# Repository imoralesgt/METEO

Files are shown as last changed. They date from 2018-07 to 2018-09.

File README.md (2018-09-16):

# METEO
## TFM MSEEI Universidad de Malaga
## Iván René Morales Argueta - 2018

===========================================================

# ToDo List
## Meteo
- [x] Connect to MQTT Broker in object constructor
	* [x] Subscribe to each ```Settings``` sub-topic ```Settings/#```
	* [ ] \(Optional) _Show performance and broker info by subscribing to special $SYS topics (https://www.hivemq.com/blog/mqtt-essentials-part-5-mqtt-topics-best-practices)_
- [x] Sample each sensor using separate threads
	* [x] Create a generic sampling method (one-shot), which receives the sensor name as parameter
		- [x] ```sampleSensor (sensorName)```
		- [x] Front-end interface variables (i.e. Air Quality, instead of Humidity+Gas_Resistance)
	- [x] Create a thread/method to periodically launch the one-shot sampling method
	* [x] Generate as many threads running this method as required
	* [ ] ~~Kill sampling threads during object destruction~~ Destructor not compatible with threaded implementation
	* [X] Implement a mutual-exclusion mechanism to avoid access violations
- [x] Send sensors' data via MQTT using topics to distribute data into different channels
- [x] Each "METEO" station MUST have a vaild (integer type) identifier, starting from 0
- [x] Topics should accomplish with the following template:
	* [x] ```METEO/<stationNumber>/Data/<sensor>```
	* [x] Valid ```<stationNumber>``` (identifiers) are integers from 0 to N-1
	* [x] Valid ```<sensor>``` values are:
		- [x] Temperature (Environmental temperature) [temp]
		- [x] Humidity (Relative humidity) [hum]
		- [x] Pressure (Local atmospheric pressure) [pres]
		- [x] Light (Incident light measurement) [light]
		- [x] AirQuality (Air quality as pollution measurement) [airQ]
		- [ ] ~~PPM (Raw particle count) [ppm]~~ PPM is irrelevant. Instead, PPM field used to transmit raw gas resistance value
- [x] A special topic may be used to set/get the sampling period dymanically
	* [x] ```METEO/<stationNumber>/Settings/SamplingRate/<sensor>```
	* [x] ```<sensor>``` field (sub-topic) is the same as described before
	* [x] Sampling rate value must be validated to remain between a valid range
		- [x] Min sampling rate 1 minute
		- [x] Max sampling rate 120 minutes
		- [x] If a sampling rate (SR) out of these limits is set, a default value will be chosen if a prior valid SR wasn't set yet; otherwise, the last valid SR will remain active
- [ ] \(Optional) _A special topic may be used to remotely reboot the device if no Alive beacons have been received_
	- [ ] _```METEO/<stationNumber>/Setiings/Reboot```_
	- [ ] _A unique key must be sent as password (through ```Reboot``` topic) to force a reboot_
	- [ ] _Key will be ```stationNumber```-dependent and time-dependent (unix format) hash_
	- [ ] _Hash must be computed by UI_
- [x] A special topic may be used to announce "I'm Alive" messages from stations to broker
	* [x] Invoke it via a separate thread as it may behave as a locking method
	* [x] ```METEO/Alive```
	* [x] Each station should publish a message containing only its ```<stationNumber>``` periodically (ie. every 1 minute)

## Printed circuit board
- [x] Design a PCB to place the sensor boards and the User-Interaction hardware (push-button + LED)
	- [x] Design must be compatible with Raspberry PI 3 header footprint
	- [x] Power must be supplied from Raspberry PI's 3v3/GND breakout pins
	- [x] Manufacture PCB and test functionality

## BME680_METEO
- [x] Compute Air Quality (%) using Humidity and Gas measurements
- [ ] ~~Compute PPM using Gas Baseline and Gas measurements~~ Not a requirement. Discarded from further releases.

## User Interaction
- [x] Add an LED status indicator to show whether the server is running or not (using RPI-GPIO)
- [x] Add a push-button input to hard-reset the server via a separate thread if anything fails (using RPI-GPIO)

## Data management
- [x] Grab sensors' data from MQTT broker and process it to deliver filtered information 
- [x] Store the processed data into a SQLite database
- [x] Retreive data from Broker and append it to a table within in the DB (running in parallel thread?)
- [x] Export table's content to a CSV when required
- [x] If several measurements from different sensors retreived within the same MINUTE, store them in the same register row.
- [x] If several measurements form the same sensor retreived within the same MINUTE, average grabbed values and then store the last average computation.

## Reliability
- [x] Run meteo.py as a standalone application
	- [x] Set flag to meteo.py
		- [x] ```chmod +x meteo.py```
- [x] Autorun on boot
	- [x] ```sudo crontab -e```
	- [x] ```@reboot /home/pi/METEO/meteo.py &```
- [x] Software Watchdog Timer
	- [x] Run a parallel process (subscribed to ```ALIVE``` topic) to check whether METEO is running or not
	- [x] Restart METEO process after 3 consecutive ```ALIVE``` periods with no answer
	- [x] Start WDT timer after the first ```ALIVE``` message arrives

# User interface
- [x] Node-RED User Interface

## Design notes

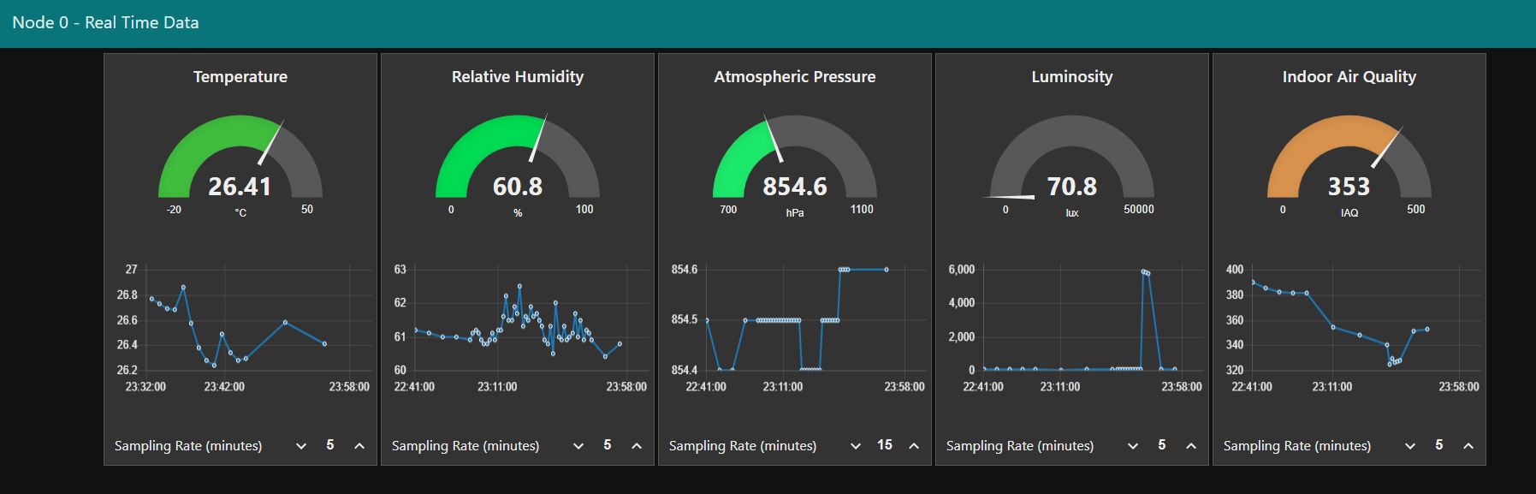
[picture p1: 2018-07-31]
gui/guiPreview.PNG

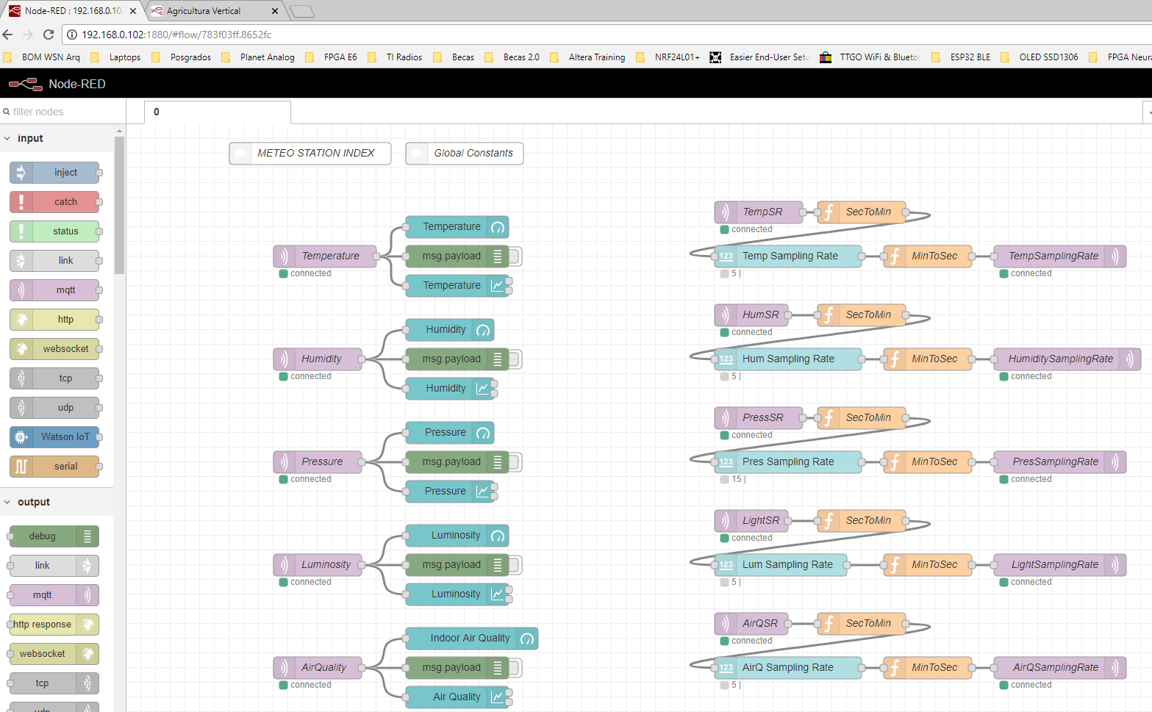
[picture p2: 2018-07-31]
gui/guiNodeRed.PNG

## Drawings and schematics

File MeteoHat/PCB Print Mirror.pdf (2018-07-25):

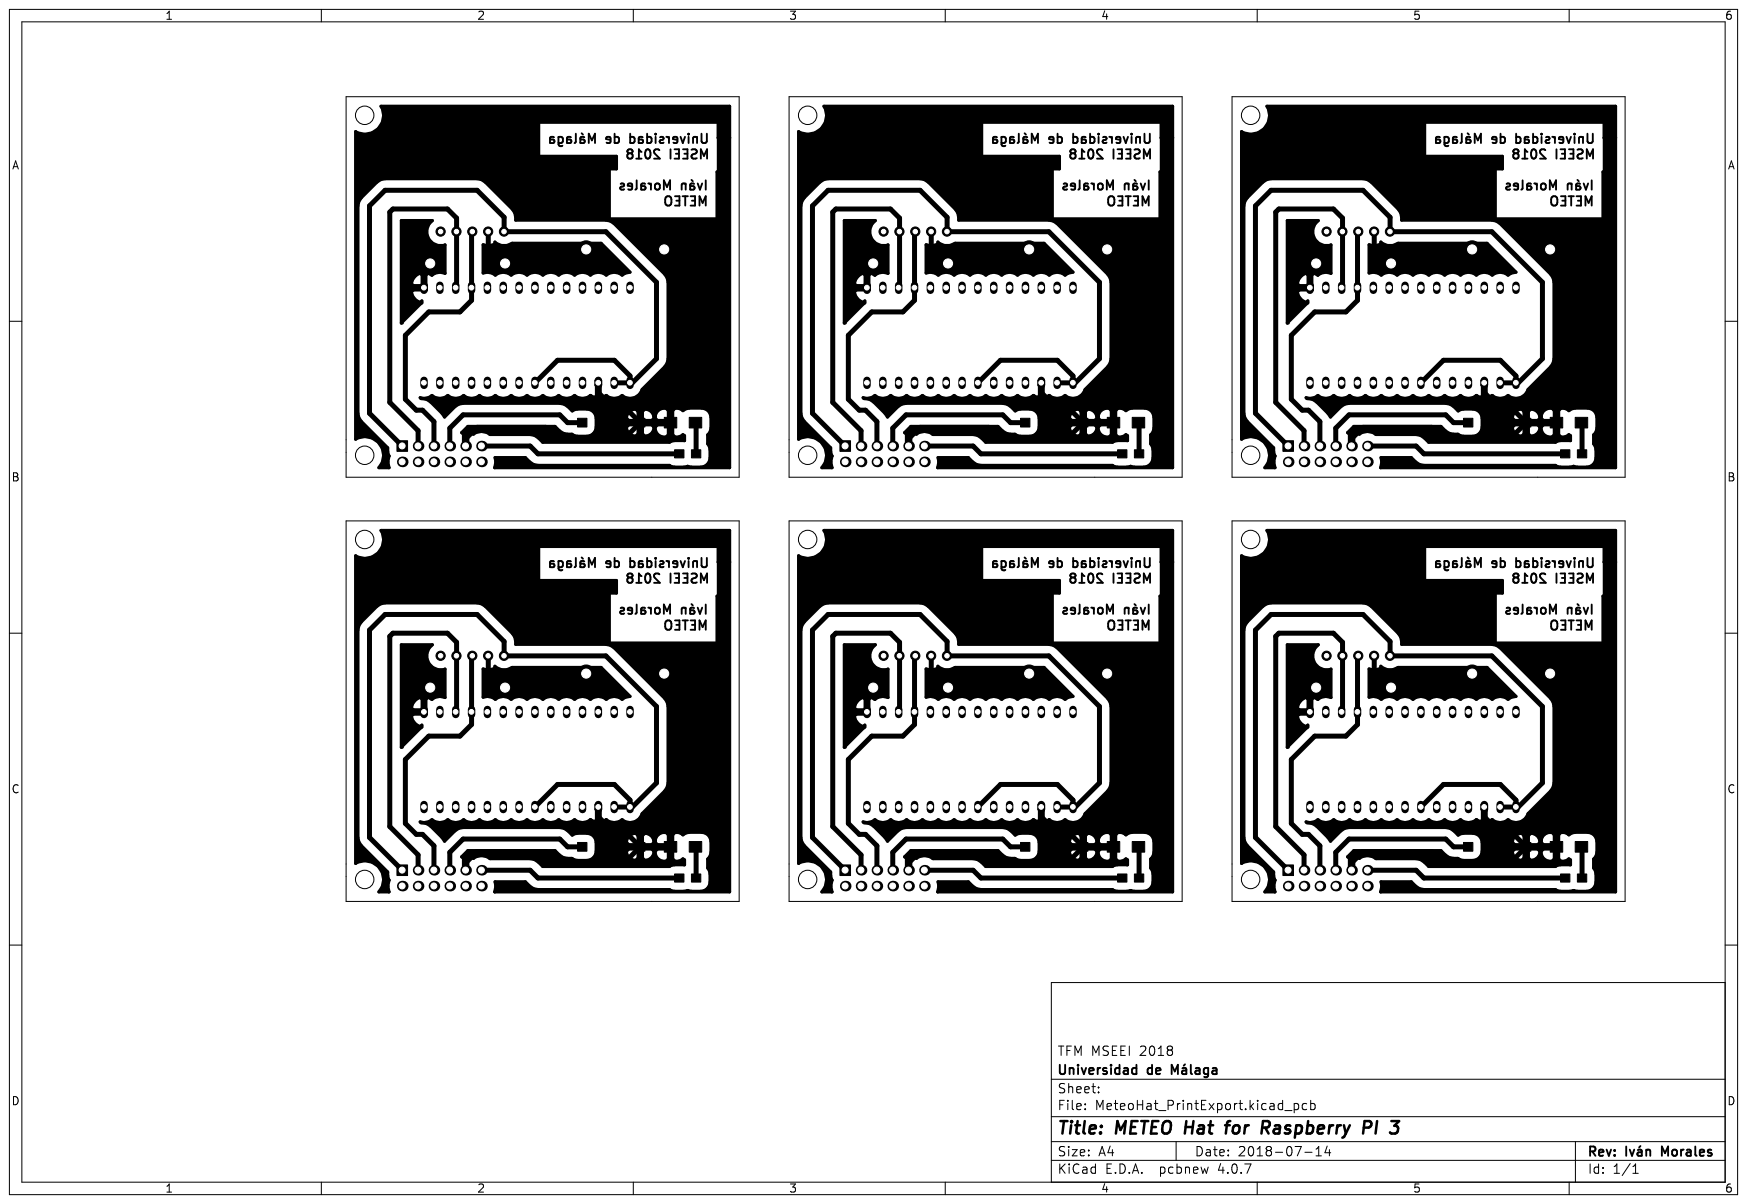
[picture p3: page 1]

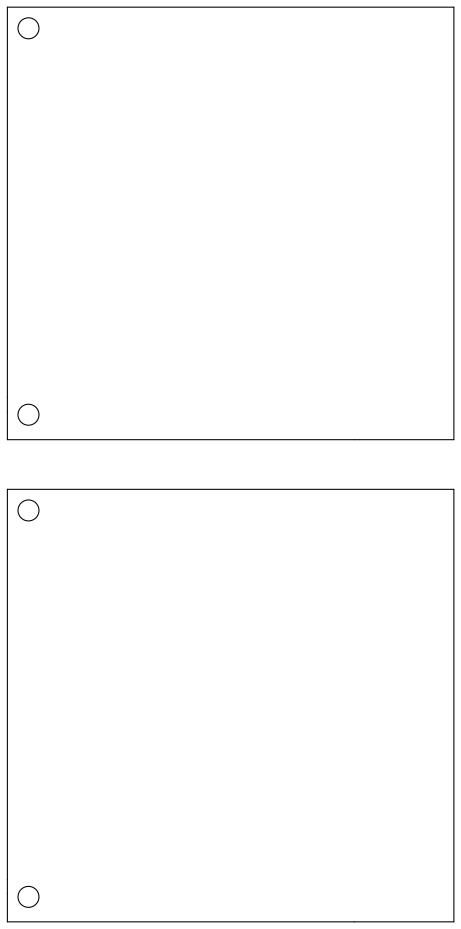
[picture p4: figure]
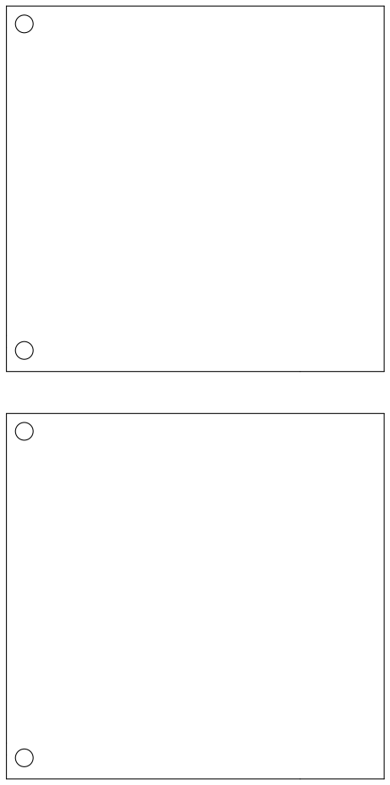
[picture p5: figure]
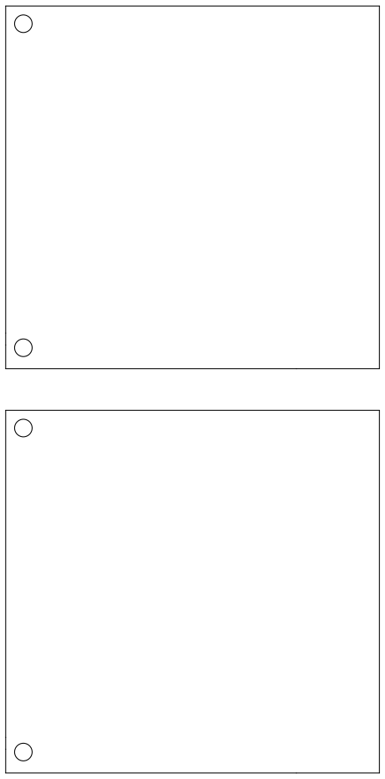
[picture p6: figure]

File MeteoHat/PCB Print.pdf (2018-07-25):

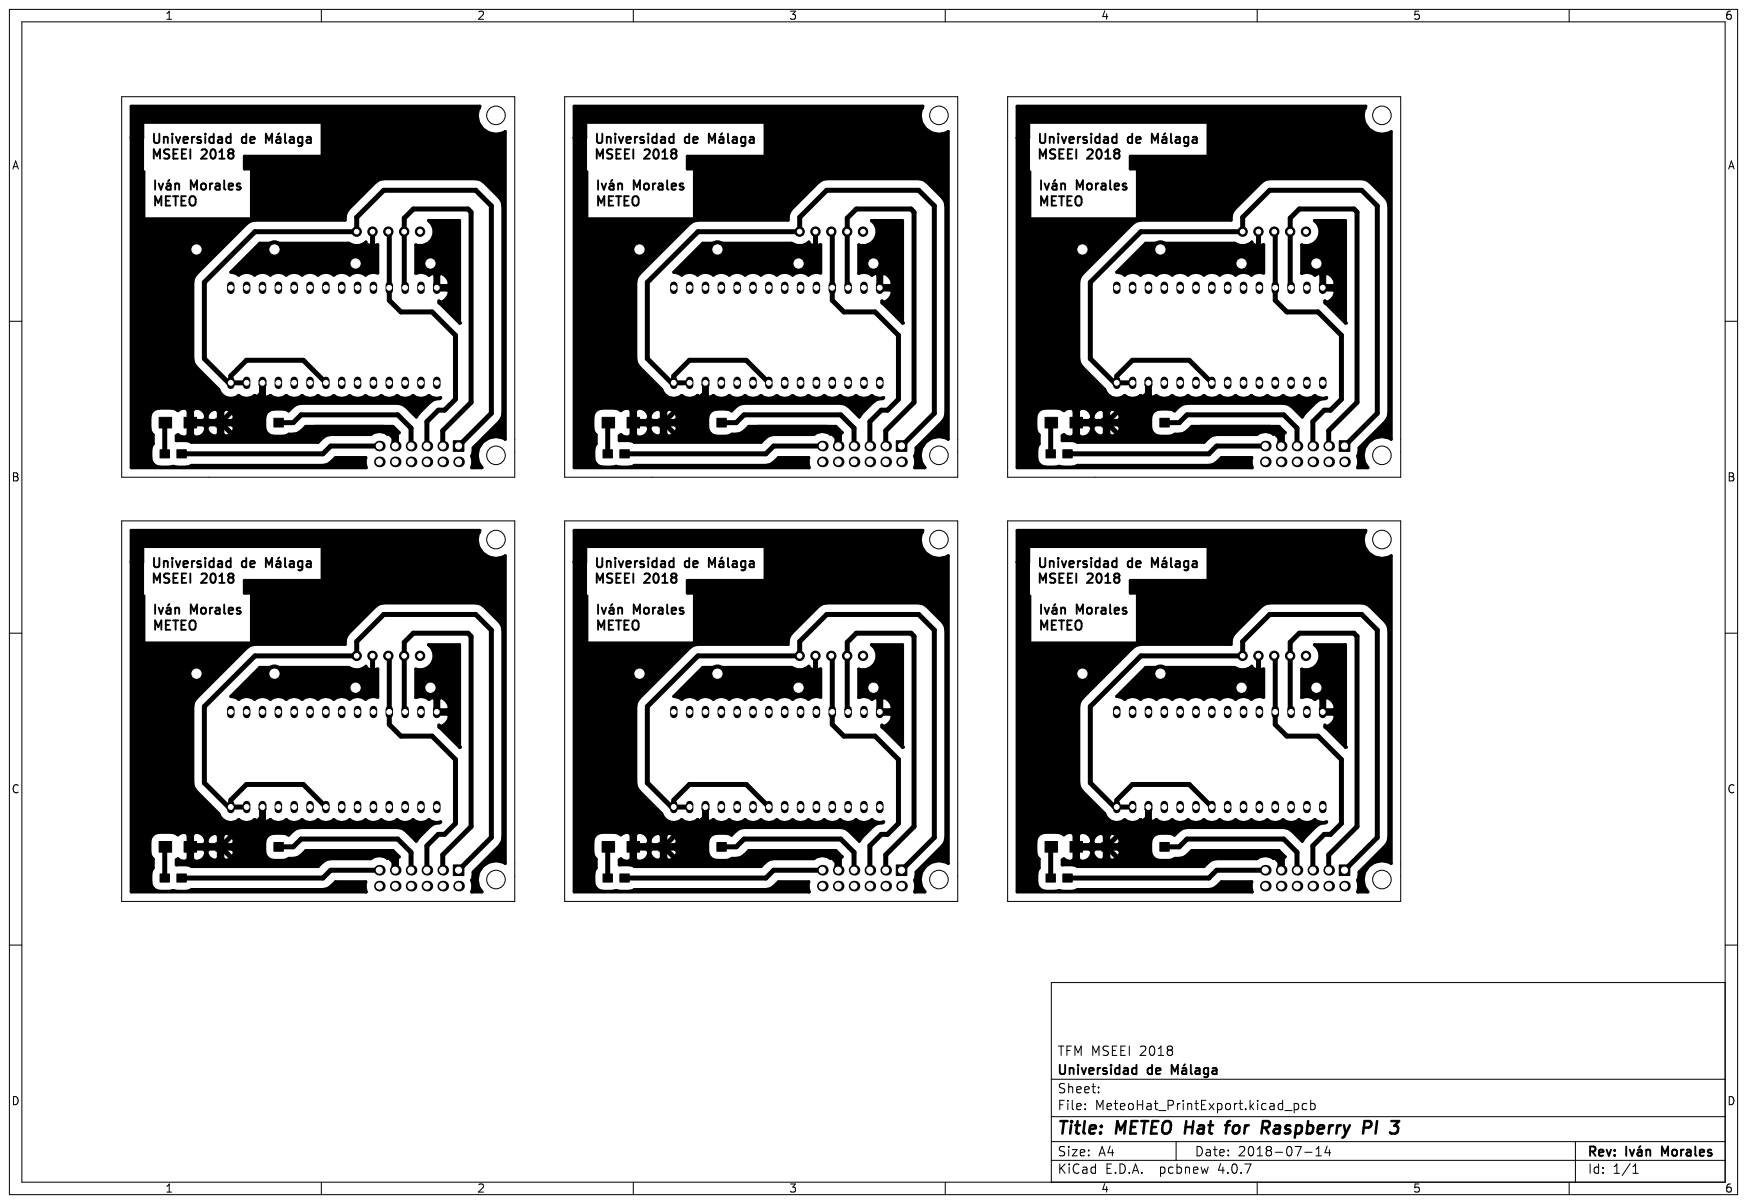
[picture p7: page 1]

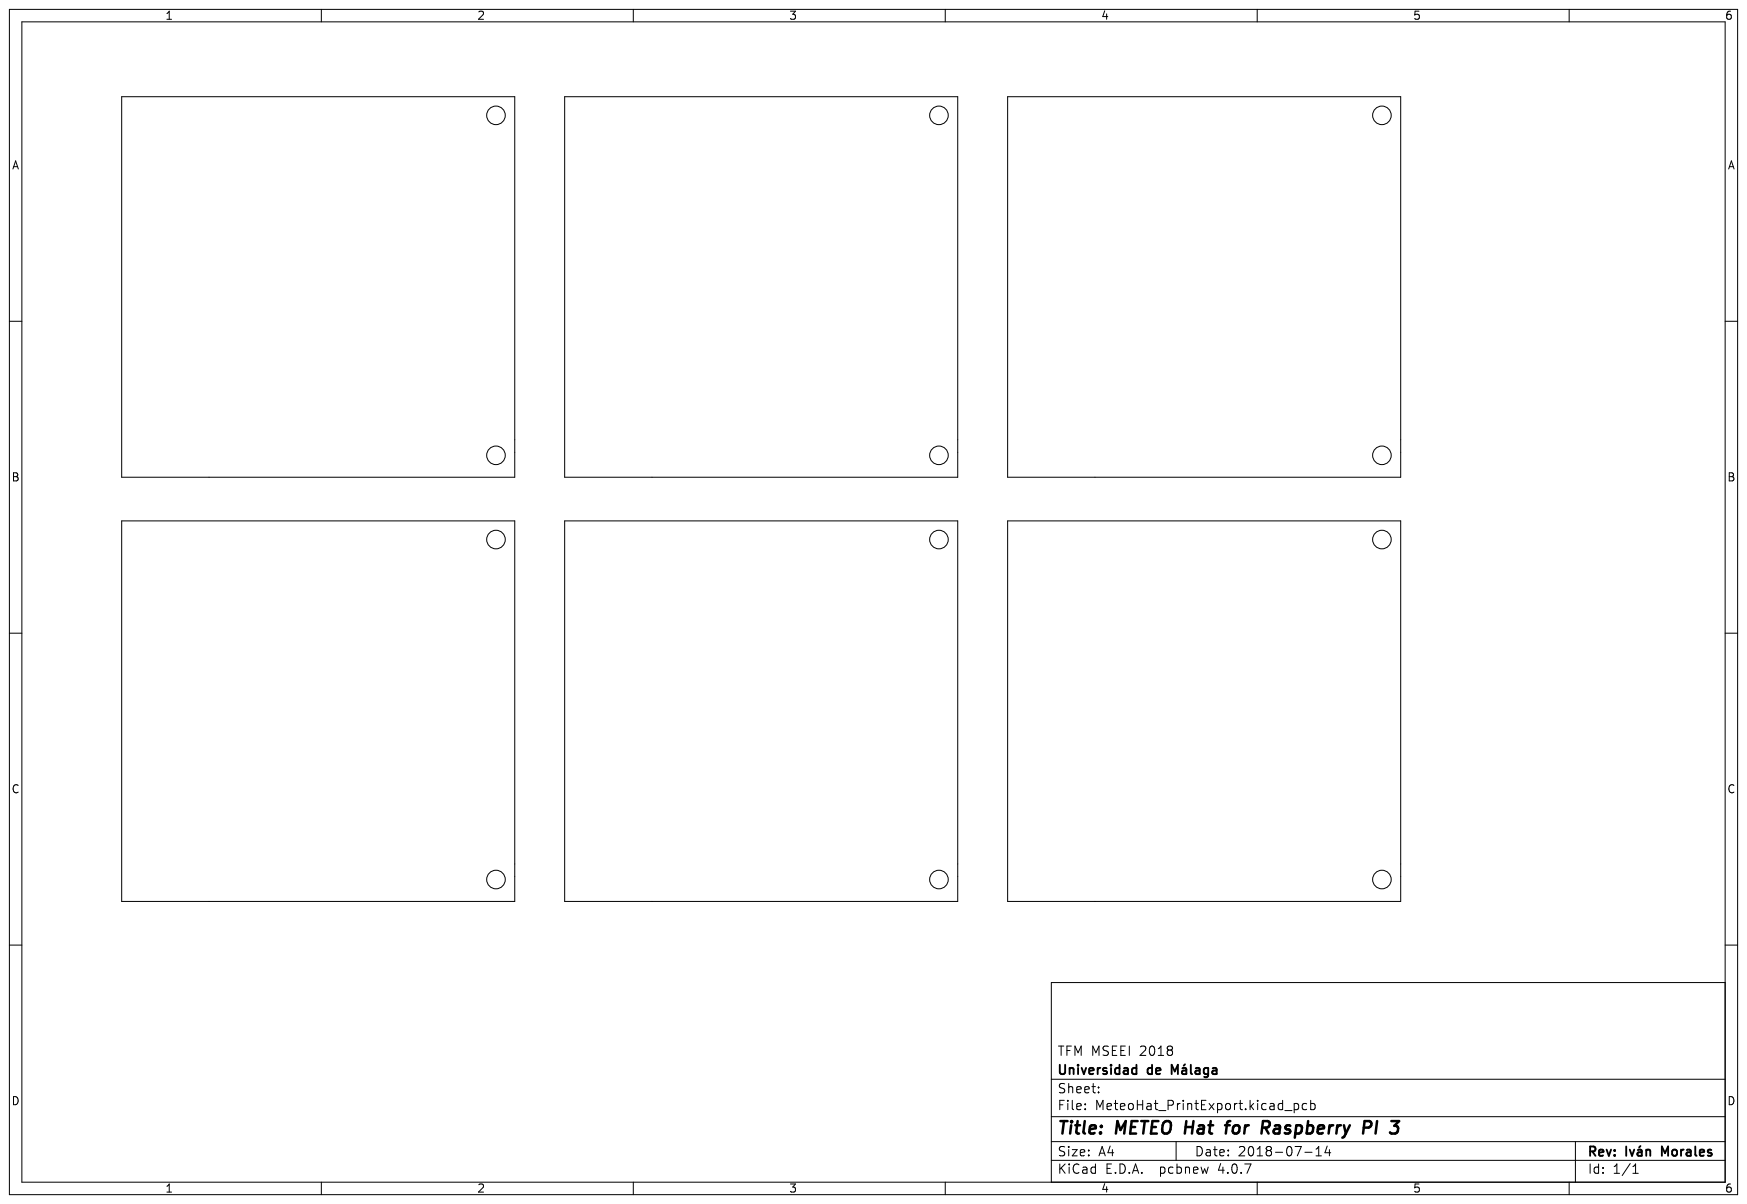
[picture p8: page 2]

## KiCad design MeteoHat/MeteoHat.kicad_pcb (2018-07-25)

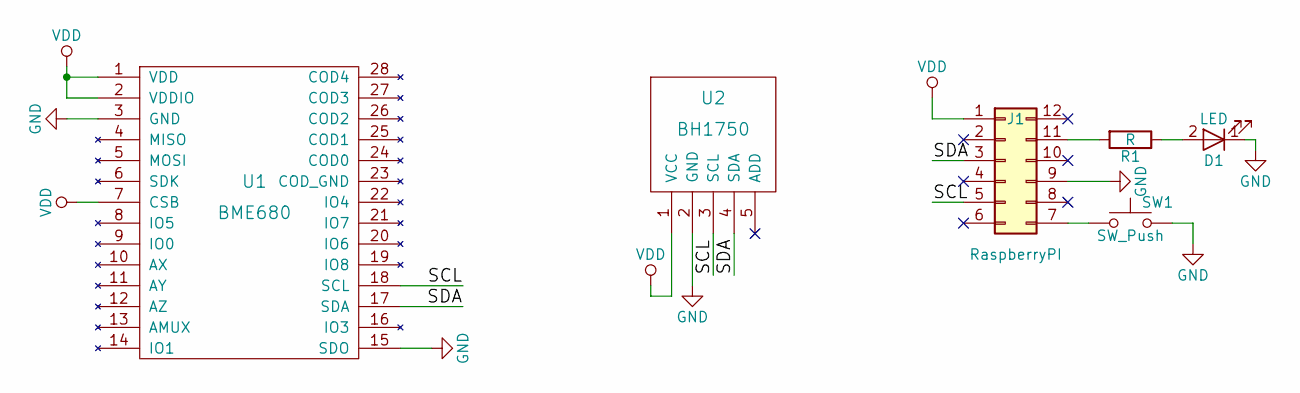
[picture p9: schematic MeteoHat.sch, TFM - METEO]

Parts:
D1: LED; LED_1206_HandSoldering
J1: RaspberryPI; Pin_Header_Straight_2x06_Pitch2.54mm
R1: R; R_0805_HandSoldering
SW1: SW_Push; 3x6x2.5mm_tact_switch
U1: BME680
U2: BH1750

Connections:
/SCL: J1.5, U1.18 (SCL), U2.3 (SCL)
/SDA: J1.3, U1.17 (SDA), U2.4 (SDA)
GND: D1.1 (K), J1.9, SW1.2, U1.3 (GND), U1.15 (SDO), U2.2 (GND)
unnamed: D1.2 (A), R1.1
unnamed: J1.7, SW1.1
unnamed: J1.11, R1.2
VDD: J1.1, U1.1 (VDD), U1.2 (VDDIO), U1.7 (CSB), U2.1 (VCC)

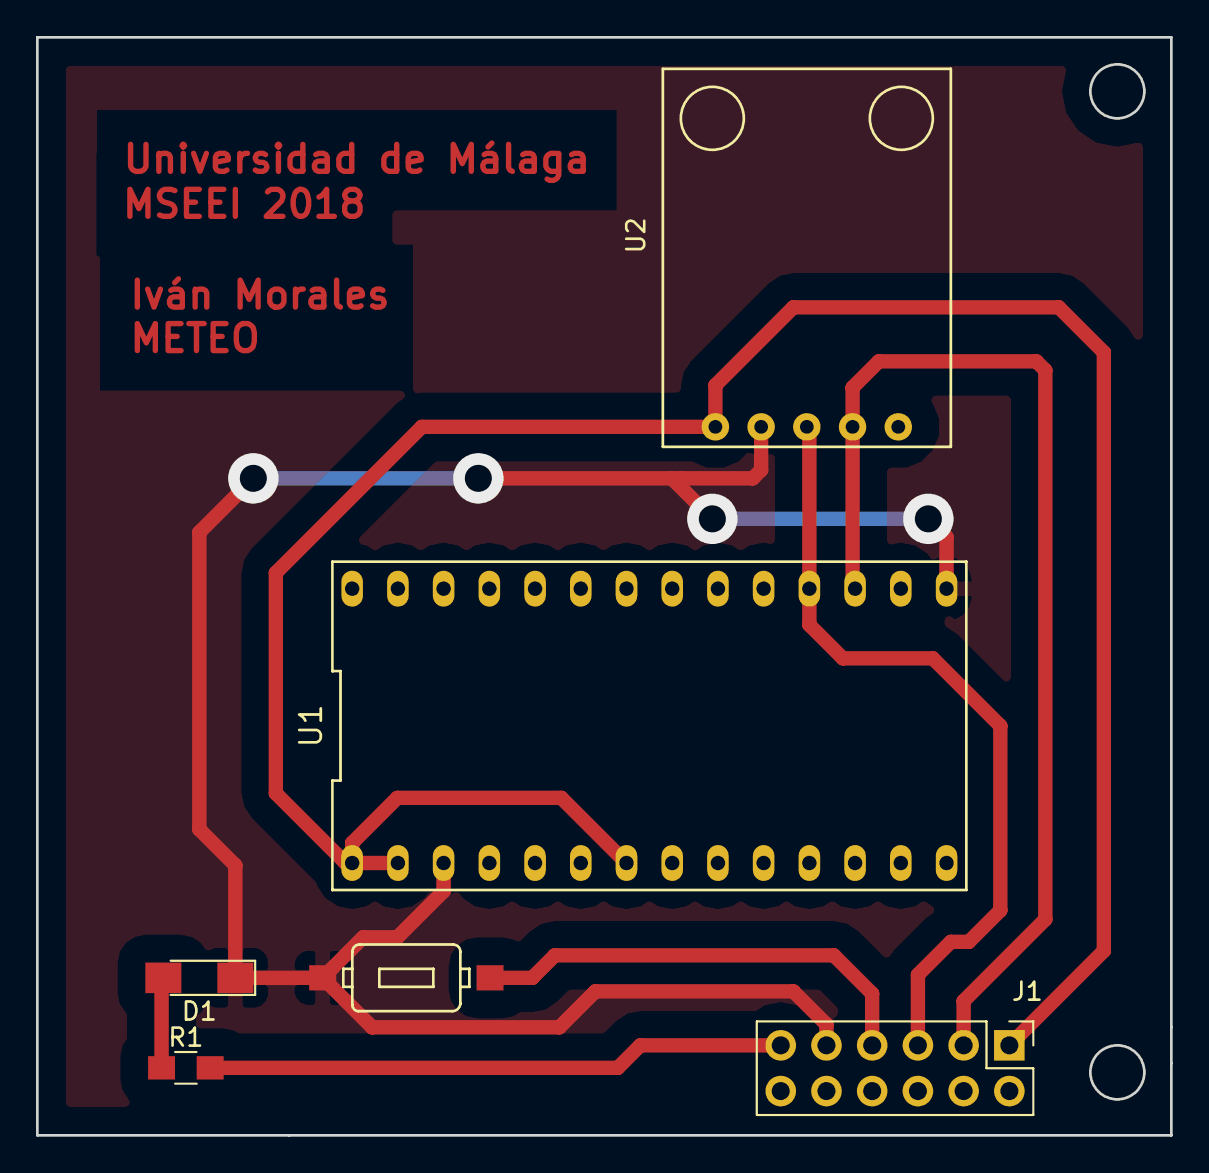
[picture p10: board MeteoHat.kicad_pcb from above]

Board: 2 copper layers, 63.0 x 61.0 mm, 6 parts (0 on the bottom side), 7 nets.

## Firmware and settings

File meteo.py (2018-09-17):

#! /usr/bin/python

'''
Third-party dependencies
-----------------------------------------------
	+ paho-mqtt (https://github.com/eclipse/paho.mqtt.python)
	+ RPi.GPIO  (https://pypi.org/project/RPi.GPIO/)
	+ SQLite 3  (https://www.sqlite.org/index.html)
'''


import paho.mqtt.client as mqttClient


import threading
import socket
import os
import time

import piSensors.BME680_METEO as BME680
import piSensors.BH1750_METEO as BH1750
from defs import * #IRM Global definitions, such as a C Header Definitions File

from ui import UI_METEO as ui # IRM LED and Push-Button interface
#from storage import *


'''
TODO list: check readme at github repo (https://github.com/imoralesgt/METEO)
'''


'''
========================================================
IRM Mutual-exclusion object to avoid simultaneous access
tries to a particular shared resource/sensor/device.

Its usage implies locking operation until the execution
queue is empty. Same object may be invoked/modified from
different threads.
========================================================
'''
class Mutex(object):

	def __init__(self, autoExec = True, DEBUG = False):
		# IRM determines whether the shared resource is locked or unlocked
		self.__locked = False 

		# IRM Queue as a list of pending executions from multiple sources
		# Each element within this list must accomplish with the following format:
		# [methodName, [list of parameters]]
		self.executionQueue = []

		# IRM Mutex is used only as a semaphore? or should it also execute pending methods?
		self.__autoExec = autoExec

		# IRM Debug enabled/disabled
		self.DEBUG = DEBUG


	'''
	=======================================================
	IRM Private methods encapsulation
	=======================================================
	'''		

	# IRM Reserved method. Updates and executes remaining (method, (parameters)) pairs if present
	def __updateLockState(self):
		if len(self.executionQueue) > 0: # IRM If there is still at least 1 pending ejecution
			self.__locked = True
			execPair = self.executionQueue.pop(0)
			if self.DEBUG:
				print execPair
			return self.__execute(execPair[0], execPair[1]) # IRM (Method, Parameters)
		else:
			self.unlock() # IRM If nothing pending, free (unlock) the resource
		
	# IRM Run a determined method with the passed parameters, which are then unpacked using (*)
	def __execute(self, method, parameters):
		data = method(*parameters) # IRM Run required method with passed parameters
		return data

	'''
	=======================================================
	IRM Public Methods
	=======================================================
	'''

	# IRM Reserve shared resource and queue a (method, [parameters]) pair
	# to be executed in a FIFO fashion. 
	def lock(self, method = None, parameters = ['Resource locked']): 
		self.__locked = True
		if self.__autoExec: # IRM Should I run something while locked?
			# IRM A tuple to represent (method, (parameters)) in queue
			self.executionQueue.append([method, parameters])

			# IRM Check whether resource is busy or not and return the
			# result of executing the queued method
			return self.__updateLockState()

	# IRM Only should be invoked by user if AutoExec is disabled!
	def unlock(self):
		if not self.__autoExec:
			self.__locked = False
			return True
		else:
			return None

	# IRM Only should be invoked by user if AutoExec is disabled!
	def isMutexLocked(self):
		if not self.__autoExec:
			return self.__locked
		else:
			return None

	def getAutoExec(self):
		return self.__autoExec


'''
=======================================================
IRM Main METEO front-end class for user-level access
=======================================================
'''
class Meteo(object):


	'''
	=======================================================
	IMR Class-related globals
	=======================================================	
	'''
	
	# IRM Variable names (Pressure, Temperature, Humidity, etc.)
	SENSOR_NAMES = AVAILABLE_SENSORS

	# IRM What variables should I measure with each sensor?
	# Temperature -> BME680
	# Pressure    -> BME680
	# Light       -> BH1750
	# Humidity    -> BME680 
	# etc ...
	SENSORS_MAP  = SENSORS_VAR_MAP

	SENSOR_BME680 = SENSOR_BME680
	SENSOR_BH1750 = SENSOR_BH1750




	'''
	=======================================================
	IRM Object constructor
	=======================================================
	'''
	def __init__(self, wdt = True, DEBUG = 0):
		self.__initSensorSR()
		self.DEBUG = DEBUG
		self.ERRORS = ERRORS
		self.setStationNumber(STATION_NUMBER)

		#IRM Change hostname
		newHostname = 'METEO-' + str(STATION_NUMBER)
		#os.system('hostname %s' % str(newHostname))

		self.__ui = ui() # IRM Hardware-related user interface (LED and Push-Button)
		self.pushThread = threading.Thread(target = self.__ui.longPressReboot, args = [], name = 'PushCheckRebootThread')
		self.pushThread.setDaemon(True)
		self.pushThread.start()
		#os.system('python ui.py &')

		#self.storageThread = threading.Thread(target = dbMain, args = [False], name = 'Storage Thread')
		#self.storageThread.setDaemon(True)
		#self.storageThread.start()
		#storageAddr = 'python ' + self.__getCurrentDir() + ' storage.py &'
		#os.system(storageAddr) # IRM Start storage process

		# IRM Mutexes to avoid multiple access tries from different threads
		self.bme680Mutex = Mutex(autoExec = True, DEBUG = False) 
		#self.bh1750Mutex = Mutex(autoExec = False)

		self.bme = BME680.BME680_METEO(DEBUG = False)
		self.bh  = BH1750.BH1750_METEO()

		self.bme.bmeInit()
		self.bh.initBH1750()

		

		self.__mqttRxMsgQueue = [] # IRM Incoming messages will be queued here
		self.__initMQTTClient()


		if wdt is not False:
			self.__launchWDT()
		

	'''
	=======================================================
	IRM Object destructor
	=======================================================
	'''
	def __del__(self):

		#IRM Kill running threads
		for i in self.samplingThread:
			if i.isAlive():
				if self.DEBUG:
					print 'Killing ' + i.getName()
				del i

		# IRM Turn LED off to show service was killed
		self.__ui.output(self.__ui.led, 0)
		del self.__ui

		

	'''
	=======================================================
	IRM Private methods encapsulation
	=======================================================
	'''

	'''
	IRM Setters and Getters
	'''

	def __getDefaultSR(self):
		return DEFAULT_SAMPLING_RATE

	def __getMinMaxSR(self):
		return (MIN_SAMPLING_RATE, MAX_SAMPLING_RATE)

	def __getCurrentDir(self):
		#return str(os.getcwd()) + '/'
		return '/home/pi/METEO/'


	'''
	IRM Other private methods
	'''

	# IRM Setup default sensor sampling rates
	def __initSensorSR(self):
		self.__SR = {}
		sensorNames = self.getSensorNames()
		for i in sensorNames:
			self.__SR[i] = self.__getDefaultSR()

	def __launchWDT(self):
		myNodeID = STATION_NUMBER
		aliveBeaconPeriod = KEEP_ALIVE_BEACON_PERIOD
		brokerAddr = MQTT_BROKER
		brokerPort = MQTT_PORT

		wdtAddress = 'python ' + self.__getCurrentDir() + 'wdt.py '

		a = os.system(wdtAddress + str(myNodeID) + ' ' + str(aliveBeaconPeriod) + ' ' + str(brokerAddr) + ' ' + str(brokerPort))

		if self.DEBUG:
			print 'Launching WDT'


	'''
	IRM MQTT-related private methods
	'''

	# IRM Connects to MQTT Broker as client
	def __setupMQTTClient(self, address, port):
		self.mqttC = mqttClient.Client(client_id="METEO"+str(self.getStationNumber())+"_METEO")

		self.mqttC.on_message = self.__mqttCallback_onMessage
		self.mqttC.on_connect = self.__mqttCallback_onConnect
		self.mqttC.on_publish = self.__mqttCallback_onPublish

		try:
			self.mqttC.connect(address, port)
		except socket.error:
			
			print 'Could not connect to Mosquitto broker at ' + str(address) + ':' + str(port)
			print 'Restarting service and trying to reconnect...'

			os.system("sudo service mosquitto restart")
			time.sleep(10)
			self.mqttC.reconnect()


	# IRM Subscribes to a determined topic using a determined QoS (QoS = 2 default)
	def __mqttSubscribe(self, topic, qos = 2):
		self.mqttC.subscribe(topic, qos)
		self.mqttThread = threading.Thread(target = self.mqttC.loop_forever, name = 'MQTT Subscriber')
		self.mqttThread.start()


	# IRM Initializes MQTT Client according to this project's requirements
	def __initMQTTClient(self):
		broker = MQTT_BROKER
		port   = MQTT_PORT


		# IRM Init MQTT Client (susbscriber)
		self.__setupMQTTClient(broker, port)


		# IRM Subscribe to every "settings" sub-topic available
		settingsTopic = ROOT_TOPIC + '/' + str(self.getStationNumber()) + '/' + SETTINGS_TOPIC + '/' + MQTT_MULTI_LEVEL
		self.__mqttSubscribe(settingsTopic)

		# IRM "Keep Alive" beacon
		self.keepAliveTopic = ROOT_TOPIC + '/' + KEEP_ALIVE_TOPIC
		keepAliveThread = threading.Thread(target = self.__mqttPublishKeepAlive, args = [KEEP_ALIVE_BEACON_PERIOD])
		keepAliveThread.start()

	# IRM Invoke one-shot publish to MQTT default broker
	def __mqttPublish(self, topic, data):
		self.mqttC.publish(topic = topic, payload = data, qos = 2)

	# IRM Keep alive beacon, should be invoked using a thread, as this is a blocking method
	def __mqttPublishKeepAlive(self, period):
		while True:
			# IRM Keep-alive beacon only contains self station number
			self.__mqttPublish(self.keepAliveTopic, self.getStationNumber())
			if self.DEBUG:
				print "I'm alive!"

			time.sleep(period) # IRM Wait for a determined time until next beacon

	# IRM Append ('Topic','Data') to Rx Queue
	def __mqttMsgQueueAppend(self, data): 
		data = (str(data[0]), data[1])
		self.__mqttRxMsgQueue.append(data)
		if self.DEBUG:
			print data

	def __mqttMsgQueueSupervisor(self):
		while True:
			if len(self.__mqttRxMsgQueue) > 0:
				queuePop = self.__mqttRxMsgQueue.pop(0)
				self.__mqttParseRxMessage(queuePop) # IRM Pop and parse first element in queue
				if self.DEBUG:
					print 'Queue popped: ' + str(queuePop)
			time.sleep(MQTT_RX_QUEUE_SUPERVISE_PERIOD)

	# IRM MQTT Received message via a subscribed topic callback
	def __mqttCallback_onMessage(self, mqttc, obj, msg): 
		self.__mqttMsgQueueAppend( (msg.topic, msg.payload) )

	# IRM MQTT Successful connection callback
	def __mqttCallback_onConnect(self, mqttc, obj, flags, rc):

		# IRM Start supervising MQTT RX Queue. If something arrives, parse it immediately
		mqttQueueSupervisorThread = threading.Thread(target = self.__mqttMsgQueueSupervisor)
		mqttQueueSupervisorThread.start()

		self.samplingThread = range(len(self.SENSOR_NAMES))

		# IRM Launch periodic sampling of connected sensors
		for i in range(len(self.SENSOR_NAMES)):
		#for i in [TEMP]:
			sensor = self.SENSOR_NAMES[i]
			self.samplingThread[i] = threading.Thread(target = self.periodicSampler, args = [sensor], name = str(sensor) + ' periodic sampler')
			self.samplingThread[i].setDaemon(True)
			self.samplingThread[i].start()
			if self.DEBUG:
				print 'Launching thread: ' + str(i)

		# IRM Turn LED on to show MQTT was successful
		self.__ui.output(self.__ui.led, 1)

		if self.DEBUG:
			print 'Connected! rc: ' + str(rc)

	# IRM MQTT Published callback
	def __mqttCallback_onPublish(self, mqttc, obj, mid):
		if self.DEBUG:
			print 'Published! mid: ' + str(mid)




	# IRM Parse received message and execute corresponding action
	# As initial subscription discards messages with <stationNumber>
	# which differ with self <stationNumber>, topic discrimination
	# will start from /Settings sub-topic
	def __mqttParseRxMessage(self, data):
		# IRM Topic example: METEO/<stationNumber>/Settings/SamplingRate/<sensor>
		topic   = data[0]
		payload = data[1]

		if SETTINGS_TOPIC in topic: # IRM Is this a config message from GUI?
			topic = str(topic.split('/'+ SETTINGS_TOPIC +'/')[1]) # IRM <operation>/<sensor>

			if self.DEBUG:
				print 'Partially parsed topic: ' + topic

			if SR_TOPIC in topic: # IRM is this a Sampling Rate config order from GUI?
				sensor = str(topic.split(SR_TOPIC + '/')[1]) # IRM Which sensor should I modify?
				if sensor in SENSOR_TOPICS_R:
					sensorName = SENSOR_TOPICS_R[sensor]
					newSR  = int(payload) # IRM Sampling Rate in seconds

					
					ok = self.setSR(sensorName, newSR)

					if self.DEBUG:
						print 'New Sampling Rate for ' + sensor + ': ' + str(newSR) + ' seconds'
						print 'Sampling rates: ' + str(self.getSRvalues())


					return ok
				else:
					if self.DEBUG:
						print 'Invalid sensor name/topic: ' + str(sensor)
						return ERRORS[INVALID_SENSOR_NAME]

	# IRM Publish formatted sensor data to MQTT Topic
	def __mqttPublishSensorValue(self, sensorName, value):
		topic = ROOT_TOPIC + '/' + str(self.getStationNumber()) + '/' + DATA_TOPIC + '/' + SENSOR_TOPICS[sensorName]


		if self.DEBUG:
			print '__mqttPublishSensorValue --- ' + str(topic) + ' : ' + str(value)

		for i in value:
			self.__mqttPublish(topic, i)



	'''
	=======================================================
	IRM Public Methods
	=======================================================
	'''

	'''
	IRM Setters and Getters
	'''

	# IRM set sampling rate in seconds.
	def setSR(self, sensor, interval):
		(minSR, maxSR) = self.__getMinMaxSR()

		sensorNames = self.getSensorNames()

		if sensor in sensorNames: # IRM Valid/Invalid sensor name
			if interval >= minSR and interval <= maxSR: # IRM Valid/Invalid interval
				self.__SR[sensor] = interval
			else:
				if self.DEBUG:
					print 'Invalid sampling rate (SR): ' + str(interval) + ' seconds'
					print 'SR must be between [' + str(minSR) + ',' + str(maxSR) + ']'
				return self.ERRORS[INVALID_SAMPLING_RATE] # IRM Invalid sampling rate
					
		else:
			if self.DEBUG:
				print 'Sensor "' + sensor + '" not valid.'
				print 'Sensor name must be one of the following in the list' + str(sensorNames)
			
			return self.ERRORS[INVALID_SENSOR_NAME] # IRM	

		return 0 # IRM No errors during operation

	def getSensorNames(self):
		return self.SENSOR_NAMES

	def getSensorMap(self):
		return self.SENSORS_MAP

	def getSRvalues(self): #IRM Sampling rate values for each sensor
		return self.__SR

	def getStationNumber(self):
		return self.stationNumber

	def setStationNumber(self, n = 0):
		if type(n) == int:
			if n >= 0:
				self.stationNumber = n
		else:
			return self.ERRORS[INVALID_STATION_NUMBER]

	'''
	IRM Other public methods
	'''

	# IRM Periodic sensor sampling method. Must be invoked from a separate thread
	def periodicSampler(self, sensorName):
		while True:
			sensorValue = self.sampleSensor(sensorName)

			if self.DEBUG:
				print 'Periodic sampler received this sample: ' + str(sensorValue)

			ok = sensorValue[0]
			if ok == True:
				value = sensorValue[1]

				# IRM Publish sensor value to MQTT Topic
				self.__mqttPublishSensorValue(sensorName, value)

			sleepInterval = self.getSRvalues()[sensorName]
			time.sleep(sleepInterval)


	# IRM Sample a determined variable in one-shot mode
	def sampleSensor(self, sensorName):
		if sensorName in self.getSensorNames():
			sMap = self.getSensorMap()
			if sMap[sensorName] == self.SENSOR_BME680:
			# IRM Measure with BME680_METEO class


				if sensorName == TEMP:
					sample = self.bme680Mutex.lock(self.bme.sampleTemperature, [])

					if sample is not False:
						return (True, [sample])
					else:
						return (False, [self.ERRORS[INVALID_TEMP_VALUE]])


				elif sensorName == HUM:
					sample = self.bme680Mutex.lock(self.bme.sampleHumidity, [])

					if sample is not False:
						return (True, [sample])
					else:
						return (False, [self.ERRORS[INVALID_HUM_VALUE]])


				elif sensorName == PRES:
					sample = self.bme680Mutex.lock(self.bme.samplePressure, [])

					if sample is not False:
						return (True, [sample])
					else:
						return (False, [self.ERRORS[INVALID_PRES_VALUE]])


				elif sensorName == AIR_Q:
					sample = self.bme680Mutex.lock(self.bme.sampleAirQuality, [])

					if sample is not False:
						return (True, [sample])
					else:
						return (False, [self.ERRORS[INVALID_AIR_Q_VALUE]])


				elif sensorName == PPM:
					sample = self.bme680Mutex.lock(self.bme.samplePPM, [])

					if sample is not False:
						return (True, [sample])
					else:
						return (False, [self.ERRORS[INVALID_PPM_VALUE]])


				else:
					return (False, [self.ERRORS[INVALID_SENSOR_NAME]])


			elif sMap[sensorName] == self.SENSOR_BH1750:
			# IRM Measure with BH1750_METEO class

				# IRM Sensor data return format:
				# (Successful measurement, [List with measurements])
				# Successful measurement : True False
				# List with measurements: 
				# If successful : List with measurements
				# If unsuccessful : List with a single element containing error code

				light = self.bh.bh1750MeasureLight()
				if light is not False:
					return (True, [light])
				else:
					return (False, [self.ERRORS[INVALID_LIGHT_VALUE]])

			else:
				return (False, self.ERRORS[INVALID_SENSOR_NAME])
		else:
			return (False, self.ERRORS[INVALID_SENSOR_NAME])



def meteoTestBench():
	try:
		#myMeteo = Meteo(True) # IRM Enable Debugging
		myMeteo = Meteo(wdt = False) # IRM Debugging disabled
	except KeyboardInterrupt:
		print 'Killing Meteo!'
		del myMeteo


if __name__ == '__main__':
	meteoTestBench()

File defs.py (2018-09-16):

'''
IRM General/Global project definitions
'''



'''
============================================================
Modify these values to setup your METEO client
Don't modify any parameter if you don't know what it means
'''
STATION_NUMBER = 0 # METEO Station Number. If this is the main station, default value is 0

#Network-related settings
MQTT_BROKER = '127.0.0.1' #MQTT broker address. If this is the main station, default value is 'localhost' or '127.0.0.1'
MQTT_PORT   = 1883 # IRM MQTT borker port. Default value is 1883


#Sensors sampling rate limits
MIN_SAMPLING_RATE     = 1   * 60 # 1 minute
MAX_SAMPLING_RATE     = 120 * 60 # 2 hours
DEFAULT_SAMPLING_RATE = MIN_SAMPLING_RATE * 5 # 5 minutes

#IRM How many days of data should be preserved in database
DB_N_DAYS			  = 30

'''
Don't modify anything else below this line
============================================================
'''




# IRM Software-level sensor names
TEMP  = 'temp'
HUM   = 'hum'
PRES  = 'pres'
LIGHT = 'light'
AIR_Q = 'airQ'
PPM   = 'ppm'

SENSOR_BME680 = 'BME680'
SENSOR_BH1750 = 'BH1750'

# IRM List of available sensors
AVAILABLE_SENSORS = [TEMP, HUM, PRES, LIGHT, AIR_Q, PPM]

# IRM Mapping measured variables to corresponding hardware sensors
SENSORS_VAR_MAP   = {TEMP : SENSOR_BME680, HUM : SENSOR_BME680,
					PRES : SENSOR_BME680, LIGHT : SENSOR_BH1750,
					AIR_Q : SENSOR_BME680, PPM : SENSOR_BME680}

'''
IRM MQTT Client-related definitions
'''
# IRM MQTT Topics/Sub-topics
ROOT_TOPIC       = 'METEO'
SENSOR_TOPICS    = {TEMP : 'Temperature', HUM : 'Humidity', PRES : 'Pressure', 
					LIGHT : 'Light', AIR_Q : 'AirQuality', PPM : 'PPM'}
SENSOR_TOPICS_R  = {'Temperature' : TEMP, 'Humidity' : HUM, 'Pressure' : PRES,
					'Light' : LIGHT, 'AirQuality' : AIR_Q, 'PPM' : PPM}
SENSOR_TOPICS_LST = (
					SENSOR_TOPICS[TEMP],
					SENSOR_TOPICS[HUM],
					SENSOR_TOPICS[PRES],
					SENSOR_TOPICS[LIGHT],
					SENSOR_TOPICS[AIR_Q]
					)

DATA_TOPIC       = 'Data'
SETTINGS_TOPIC   = 'Settings'
SR_TOPIC         = 'SamplingRate'
KEEP_ALIVE_TOPIC = 'Alive'

MQTT_SINGLE_LEVEL = '+'
MQTT_MULTI_LEVEL  = '#'

# IRM MQTT-related clients' settings
IDENTIFIER_TOPIC_TYPE = int
MAX_CLIENTS = 256




# IRM other MQTT-related defines
KEEP_ALIVE_BEACON_PERIOD = 30 # IRM Send beacon every 30 seconds
MQTT_RX_QUEUE_SUPERVISE_PERIOD = 0.1 # IRM Check input queue every 100 ms

'''
IRM Other METEO settings
'''


'''
IRM Errors list
'''
INVALID_SAMPLING_RATE  = 'INVALID_SAMPLING_RATE'
INVALID_SENSOR_NAME    = 'INVALID_SENSOR_NAME'
INVALID_STATION_NUMBER = 'INVALID_STATION_NUMBER'
INVALID_LIGHT_VALUE    = 'INVALID_LIGHT_VALUE'
INVALID_TEMP_VALUE     = 'INVALID_TEMP_VALUE'
INVALID_HUM_VALUE      = 'INVALID_HUM_VALUE'
INVALID_PRES_VALUE     = 'INVALID_PRES_VALUE'
INVALID_AIR_Q_VALUE    = 'INVALID_AIR_Q_VALUE'
INVALID_PPM_VALUE      = 'INVALID_PPM_VALUE'

ERRORS = {
		 INVALID_SAMPLING_RATE  : -1, INVALID_SENSOR_NAME : -2,
		 INVALID_STATION_NUMBER : -3, INVALID_LIGHT_VALUE : -4,
		 INVALID_TEMP_VALUE     : -5, INVALID_HUM_VALUE   : -6,
		 INVALID_PRES_VALUE     : -7, INVALID_AIR_Q_VALUE : -8, 
		 INVALID_PPM_VALUE      : -9
		 }

'''
IRM Data storage settings
'''
METEO_DATA_FOLDER   = 'data'
METEO_FILENAME_ROOT = 'METEO_'
METEO_FILE_FORMAT   = '.csv'
CSV_HEADER          = 'Date, Time, METEO_ID, Temperature, Humidity, Pressure, Luminosity, Air Quality,'
DB_FILE_NAME		= 'meteo.db'
DB_TABLE_NAME	    = 'meteo'
DB_TABLE_FIELDS     = ('Date', 'Time', 'Node', SENSOR_TOPICS[TEMP], SENSOR_TOPICS[HUM],
						 SENSOR_TOPICS[PRES], SENSOR_TOPICS[LIGHT], SENSOR_TOPICS[AIR_Q] )

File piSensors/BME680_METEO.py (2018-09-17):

import bme680 #IRM Based on Pimoroni's BME680 Python Wrapper

import threading #IRM Non-blocking gas sensor burn-in thread
import time #IRM Sleep and not-that-accurate time measurement

from sensorDefs import * #IRM Sensors-related constants

class BME680_METEO(object):

	'''
	=======================================================
	IMR Class-related globals
	=======================================================	
	'''


	'''
	IRM 'Private' globals
	'''

	__temp = 'TEMPERATURE'
	__hum  = 'HUMIDITY'
	__pres = 'PRESSURE'
	__gas  = 'GAS'


	#IRM Gas sensor burn-in time before it becomes operative
	__GAS_BURN_IN_TIME = GAS_BURN_IN_TIME


	#IRM Gas sensor's heater settings
	__GAS_HEATER_TEMPERATURE = GAS_HEATER_TEMPERATURE
	__GAS_HEATER_DURATION    = GAS_HEATER_DURATION
	__GAS_HEATER_PROFILE     = GAS_HEATER_PROFILE

	#IRM IAQ-related constants
	__IAQ_MAX_GAS = IAQ_MAX_GAS # IRM Max gas resistance value
	__IAQ_MIN_GAS = IAQ_MIN_GAS # IRM Min gas resistance value
	__IAQ_MIN_HUM = IAQ_MIN_HUM # IRM Min relative humidity
	__IAQ_MAX_HUM = IAQ_MAX_HUM # IRM Max relative humidity
	__IAQ_OPT_HUM = HUM_BASELINE # IRM Optimal relative humidity
	__IAQ_OPT_GAS = GAS_OPTIMAL  # IRM Optimza gas resistance

	__IAQ_HUM_CONTRIBUTION = IAQ_HUM_CONTRIBUTION
	__IAQ_GAS_CONTRIBUTION = IAQ_GAS_CONTRIBUTION



	'''
	=======================================================
	IRM Object constructor
	=======================================================
	'''

	def __init__(self, DEBUG = False):
		
		#IRM How many measurements used to compute gas baseline
		if(GAS_BASELINE_MEASUREMENTS > self.__GAS_BURN_IN_TIME):
			self.__GAS_BASELINE_MEASUREMENTS = self.__GAS_BURN_IN_TIME
		else:
			self.__GAS_BASELINE_MEASUREMENTS = GAS_BASELINE_MEASUREMENTS

		self.__HUM_BASELINE = HUM_BASELINE #IRM Ideal indoor relative humidity


		self.__DEBUG = DEBUG

		if DEBUG:
			print 'Gas sensor burn-in time (seconds): ' + str(self.__GAS_BURN_IN_TIME)
			print 'Gas sensor baseline measurements (seconds): ' + str(self.__GAS_BASELINE_MEASUREMENTS)
			print 'Ideal indoor relative humidity (%): ' + str(self.__HUM_BASELINE)
 

		self.bme = bme680.BME680()

		self.__gasReadable = False #IRM Gas sensor status. True until burn-in time reached
		self.__burnInData = [] #IRM Burn-in data used to set the average gas resistance value

		self.__gasBaseLine = 0 #IRM Gas resistance baseline value after burn-in process ended

		self.sensorData = {}

		if self.__DEBUG: #IRM Print out calibration DATA if Debug mode is enabled
			print("Calibration data:")

			for name in dir(self.bme.calibration_data):
					if not name.startswith('_'):
						value = getattr(self.bme.calibration_data, name)

						if isinstance(value, int):
							print("{}: {}".format(name,value))

	'''
	=======================================================
	IRM Private methods encapsulation
	=======================================================
	'''

	'''
	IRM Setters and Getters
	'''

	def __getGasState(self):
		return self.__gasReadable

	def __setGasState(self, readable):
		if(type(readable) == bool):
			self.__gasReadable = readable
		else:
			self.__gasReadable = False

	'''
	IRM Other private methods
	'''

	def __clearBurnInData(self):
		self.__burnInData = []

	# IRM Must NOT allow high-level access to gas sensor burn-in process
	def __gasBurnIn(self, burnInTime): #IRM Initialize Gas Sensor in a non-blocking action
		startTime = time.time()
		currentTime = time.time()

		self.__clearBurnInData()

		if self.__DEBUG:
			print 'Gas sensor burn-in process running in background...  ' + str(self.__GAS_BURN_IN_TIME) + ' seconds'



		while currentTime - startTime < burnInTime:
			currentTime = time.time()
			if self.bme.get_sensor_data and self.bme.data.heat_stable:
				gas = int(self.bme.data.gas_resistance)
				self.__burnInData.append(gas)
				time.sleep(1)

				if self.__DEBUG:
					print 'Gas sensor burn-in process running... (' \
					 + str(int(currentTime - startTime)) + ' out of ' + str(burnInTime) + ' seconds passed)'

		#IRM After burn-in time has been reached, set 'gasReadable' as True
		if self.__DEBUG:
			print 'Gas sensor is ready!'

		self.__setGasState(True)

		#IRM Also, set the gas baseline value for further measurements
		gasBaseLine = sum(self.__burnInData[-self.__GAS_BASELINE_MEASUREMENTS:]) / float(self.__GAS_BASELINE_MEASUREMENTS)
		self.setBaseLineValue(gasBaseLine)

		if self.__DEBUG:
			print 'Gas baseline value: ' + str(self.getBaseLineValue())

	'''
	=======================================================
	IRM Public Methods
	=======================================================
	'''

	'''
	IRM Setters and Getters
	'''
	def getBaseLineValue(self):
		return self.__gasBaseLine

	def setBaseLineValue(self, value):
		try:
			self.__gasBaseLine = value
		
		except TypeError:
			self.__gasBaseLine = 0
			print 'Invalid Gas Baseline Value Type. Must be an Int/Float'
			print 'Argument type: ' + str(type(value))


	'''
	IRM Other public methods
	'''

	def killBurnInDaemon(self):
		if self.burnInThread.isAlive(): #IRM Is burn-in thread still running?
			del self.burnInThread
			return True

		return False #IRM Ok, I didn't do anything anyways. Suicide thread has killed itself before I arrived.


	def bmeInit(self): #IRM Initialize BME680 with default sampling settings
		self.bme.set_humidity_oversample(bme680.OS_2X)
		self.bme.set_pressure_oversample(bme680.OS_4X)
		self.bme.set_temperature_oversample(bme680.OS_8X)
		self.bme.set_filter(bme680.FILTER_SIZE_3)
		self.bme.set_gas_status(bme680.ENABLE_GAS_MEAS) #IRM Enable gas resistance measurement for air-quality data

		if self.__DEBUG:
			print '\n\nInitial reading:'
			for name in dir(self.bme.data):
				value = getattr(self.bme.data, name)

			if not name.startswith('_'):
				print("{}: {}".format(name, value))

		#IRM Setup gas heater profile 
		self.bme.set_gas_heater_temperature(self.__GAS_HEATER_TEMPERATURE)
		self.bme.set_gas_heater_duration(self.__GAS_HEATER_DURATION)
		self.bme.select_gas_heater_profile(self.__GAS_HEATER_PROFILE)

		#IRM Start gas sensor burn-in process in a non-blocking thread
		self.burnInThread = threading.Thread(target = self.__gasBurnIn, args=(self.__GAS_BURN_IN_TIME,), name = 'Gas Sensor Burn-In', )
		self.burnInThread.setDaemon(True) #IRM Run in background
		self.burnInThread.start() #IRM Suicide thread. Will kill itself after burn-in time has concluded

	def getSensorObject(self):
		return self.bme

	#IRM Return BME680 measurements. Gas measurment will be done only when heater is ready
	def getSensorData(self, temp = False, hum = False, pres = False, gas = False):
		sensor = self.getSensorObject()

		if sensor.get_sensor_data():

			if temp:
				self.sensorData[self.__temp] = float('{:.2f}'.format(sensor.data.temperature))

			if hum:
				self.sensorData[self.__hum]  = float('{:.1f}'.format(sensor.data.humidity))

			if pres:
				self.sensorData[self.__pres] = float('{:.1f}'.format(sensor.data.pressure))
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

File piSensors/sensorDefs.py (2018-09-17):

'''
=======================================================
IRM BME680 Defines
=======================================================
'''
GAS_HEATER_TEMPERATURE = 320 #IRM BME680's gas heater operating temperature
GAS_HEATER_DURATION    = 150 #IRM BME680's gas heater startup duration (microseconds)
GAS_HEATER_PROFILE     = 0   #IRM BME680's chosen gas heating profile


GAS_BURN_IN_TIME = 300 #IRM Burn-in time (seconds) before gas sensor is operative (default: 5 minutes)
GAS_BASELINE_MEASUREMENTS = 50 #IRM How many gas sensor measurements should be used for average GAS_BASELINE_MEASUREMENT

HUM_BASELINE = 40 #IRM Optimal indoor relative humidity percentage (default: 40%)


IAQ_MAX_GAS = 250000 # IRM Max gas resistance measurement
IAQ_MIN_GAS = 50    # IRM Min gas resistance measurement
IAQ_MIN_HUM = 0     # IRM Min relative humidity
IAQ_MAX_HUM = 100   # IRM Max relative humidity

GAS_OPTIMAL = IAQ_MAX_GAS

IAQ_HUM_CONTRIBUTION = 0.25 # IRM Humidity contribution to Index of Air Quality
IAQ_GAS_CONTRIBUTION = 1 - IAQ_HUM_CONTRIBUTION # IRM Gas contribution to Index of Air Quality

'''
=======================================================
IRM BH1750 Defines
=======================================================
'''
DEFAULT_LIGHT_SENSITIVITY = 69
DEFAULT_LIGHT_I2C_ADDRESS = 0x23

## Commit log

2018-06-18 Added non-blocking gas sensor burn-in daemon
    - The rest of the sensors start measuring immediately after BME680 is initialized. Gas sensor is burned-up until burn-in time (default: 5 minutes) pass by.
    - Added external constants file for easy sensor configuration (sensorDefs.py).
    - Class was completely reordered to easily accomodate further changes in a much more robust and modular way.
    [BME680_METEO.py, meteo.py, sensorDefs.py]
2018-06-20 Added light sensor import
2018-06-20 Added light sensor-related defines
2018-06-20 BH1750 Light sensor high level fault-tolerant library
    Default 0.5 lux resolution and 0x23 I2C Address Map
2018-07-02 Work started under METEO main class
    - Requirements have been defined in the initial comments
    - Standarization of available sensors and sampling rate manipulation methods have been written
    - MQTT Client connection to broker has been implemented, including service restart if connection to broker fails
    [BME680_METEO.py, defs.py, meteo.py]
2018-07-12 Fixed some typos in the comments
    [meteo.py]
2018-07-14 PCB for Raspberry PI Hat
    [MeteoHat.kicad_pcb, MeteoHat.sch, MeteoHat_PrintExport.kicad_pcb]
2018-07-14 Some minor tests done with MQTT Broker
    [meteo.py]
2018-07-15 Fixed BME680 HAL to support threading
    [BME680_METEO.py]
2018-07-15 Added some error definitions
    [defs.py]
2018-07-15 Implemented mutual-exclusion (MUTEX) mechanism
    - Implemented MUTEX with/without autoexecution of threads in queue
    - Mutex tests have been passed using a shared resource (BME680) in up to 20 (MAX_TASKS) concurrent threads where temperature was measured
    - Implemented one-shot measurement of front-end variables (temperature, air quality, ppm, presure, humidity, luminosity), which relay on back-end variables (gas resistor, thermometer, etc)
2018-07-16 MQTT Subscription/Publishing functionality added
    - Sampling rate can be individualy set for each sensor
    - Publishing sensor values still not working, mutex implemented and tested
    [meteo.py]
2018-07-23 Fixed unsampled sensors Null data, now returning False if no sensor data available
    [BME680_METEO.py]
2018-07-23 Sensor data published in separate threads as described in requirements
2018-07-24 Implemented Air Quality Index computation (IAQ). PPM is irrelevant
    IAQ in a 0 to 500 range, where 500 is worst.
    PPM measurements used to display raw gas resistance value
2018-07-25 Added RPi GPIO-based Low-levelUser Interaction with LED and Push-Button
2018-07-25 Showing via LED broker connection status
    LED On: Connected to broker
    LED Off: Disconnected from broker
    [meteo.py]
2018-07-25 Added PCB Keepout Zones
    [MeteoHat.kicad_pcb, MeteoHat_PrintExport.kicad_pcb]
2018-07-26 Added reboot feature while depressing push button during 30 seconds
    METEO Autorun has been enabled during boot time
    [meteo.py, ui.py]
2018-07-28 Fixed BME680 max gas sensor resistance value
    [sensorDefs.py]
2018-07-28 User-defined settings in 'defs.py' file now easier to modify
    User can now easily modify 'defs.py' file to setup METEO station parameters, such as broker address/port and sampling rate ranges.
    [defs.py]
2018-07-28 Fixed BME680 gas resistance range
    [BME680_METEO.py, sensorDefs.py]
2018-07-28 Fixed and tested WDT implementation
    [meteo.py, wdt.py]
2018-07-31 First GUI commit
    Using Node-RED with Dashboard controls.
    - Displays real time data
    - Displays historic graph
    - Sampling rate (SR) can be changed from gui
    - Coherence of SR display (if changed in from a different device, displayed value changes too)
2018-08-01 Fixed typo in comments
    [defs.py]
2018-08-02 Implemented StorageQueue - Not tested yet
    StorageQueue to avoid leaving register fields in blank if data arrives within a 1 minute window.
    [defs.py, storage.py]
2018-09-02 Fixed bugs. Now writting to register data in sync
    SQL Implementation left. However, data is already formatted and gathered so it shouldn't be a big deal. Old data deletition every new day still needs to be implemented.
    [defs.py, storage.py]
2018-09-04 Fixed unsent data to register queue
    [storage.py]
2018-09-10 Fixed paths for autostart on boot
    Now working everything, storing data and deleting old records.
    Only Node-Red FTP CSV File download missing.
    [meteo.csv]
2018-09-12 NodeRed UI
    [meteo.csv]
2018-09-12 Storage launched as a thread, not as a parallel process anymore
2018-09-16 Fixed default sampling rate | Reduced ALIVE beacon period downto 30 seconds | Added sh startup script | Backed Node-Red UI up
    [MeteoHat.sch]
2018-09-17 Small fixes to test subsystems' functionality
    [BH1750_METEO.py, BME680_METEO.py, meteo.py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]
